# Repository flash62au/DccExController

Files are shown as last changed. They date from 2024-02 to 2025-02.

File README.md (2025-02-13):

# DccExController

Please note:

* For the foreseeable future I will not be maintaining this code base.  <br> I would recommend switching to [WiTcontroller](https://github.com/flash62au/WiTcontroller)
* I will not be providing any support for this code.
* I am no longer contactable on the DCC-EX Discord server.
* As always, you are welcome to [fork the code](forking.md) and do with it as you wish, within the limits of the licence.

## Description

A DccExController is a simple DIY, handheld controller that talks to a wThrottle Server (JMRI, DCC++EX and many others) using the Native DCC-EX protocol, exclusive to the EX-CommandStations, to control DC and DCC model trains. 

[3d Printed Case](https://www.thingiverse.com/thing:5440351)

---

## Prerequisites

1. Some basic soldering skills.  

    The components will work if just plugged together using jumpers, but they take a lot of space that way, so soldering them together is advised to make it hand held.

2. Loading the code (sketch) requires downloading of one of the IDEs, this sketch, the libraries, etc. so some experience with Arduinos is helpful, but not critical.

3. An EX-CommandStation to connect to. DccExController will ONLY work with any EX-CommandStations!
---

## Building

### Required Components

* WeMos Lite LOLIN32  (ESP32 Arduino with LiPo charger) ([Example](https://www.ebay.com.au/itm/284800618644?hash=item424f709094:g:-soAAOSwHslfC9ce&frcectupt=true))
* 3x4 Keypad  ([Example](https://www.jaycar.com.au/12-key-numeric-keypad/p/SP0770?pos=2&queryId=20aedf107668ad42c6fe1f8b7f7a9ca7))
* Polymer Lithium Ion Battery LiPo 400mAh 3.7V 502535 JST Connector (or larger capacity) ([500mAh Example](https://www.ebay.com.au/itm/133708965793?hash=item1f21ace7a1:g:tlwAAOSwfORgYqYK))
* KY-040 Rotary Encoder Module ([Example](https://www.aliexpress.com/item/1005003946689694.html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))
* OLED Display 0.96" 128x64 Blue I2C IIC SSD1306 ([Example](https://www.ebay.com.au/itm/273746192621?ssPageName=STRK%3AMEBIDX%3AIT&_trksid=p2060353.m2749.l2649))
* Case - my one was 3d printed (see below)
* Knob ([Example](https://www.jaycar.com.au/35mm-knob-matching-equipment-style/p/HK7766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))
* Wire - If you plan to solder the connections,which is the recommended approach, then stranded, coloured wire is advisable.  ([Example](https://www.jaycar.com.au/rainbow-cable-16-core-sold-per-metre/p/WM4516))

### Optional Components

* Optional: Up to 7 additional push buttons can be added, each with their own independent commands. ([Example](https://www.jaycar.com.au/red-miniature-pushbutton-spst-momentary-action-125v-1a-rating/p/SP0710))
* Optional: A 1.3" OLED Display 128x64 can be used instead of the 0.96" OLED Display 128x64 ([Example](https://www.aliexpress.com/item/32683094040.html?spm=a2g0o.order_list.order_list_main.110.25621802jRBB7y)) Note: You will need to make a small configuration change for this to work correctly.
* Optional: You can use a 4x4 keypad instead of the 3x4 keypad. Note: You will need to make a small configuration change in ``config_buttons.h`` for this to work correctly.

### Pinouts

*Standard Configuration Pinouts*
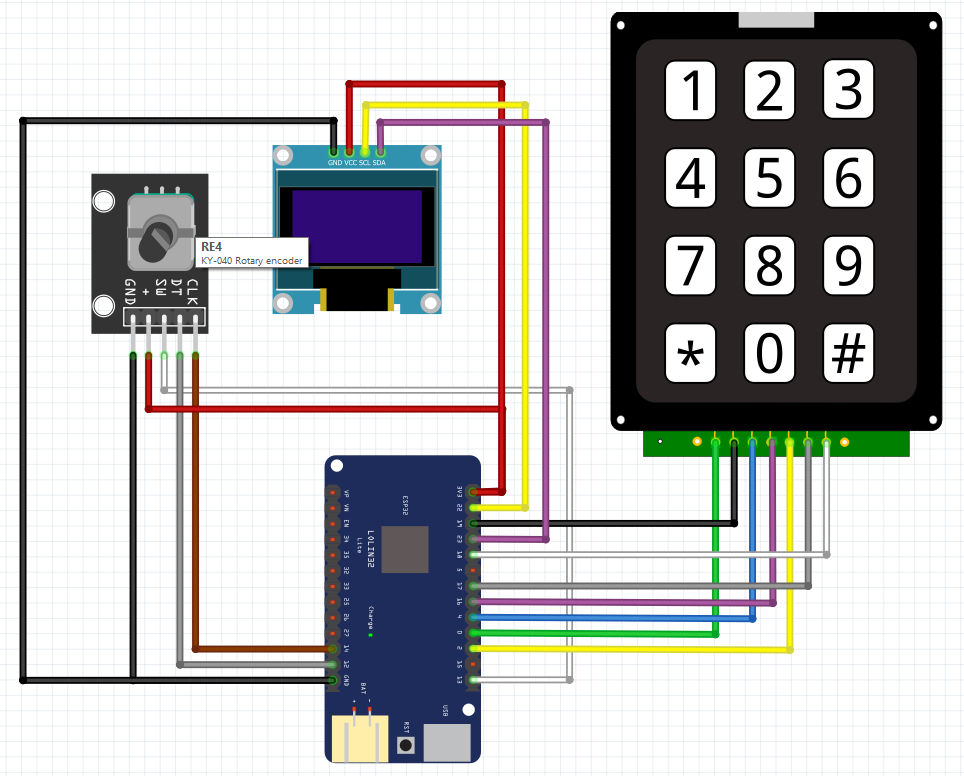
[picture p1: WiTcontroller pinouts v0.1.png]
Assembly diagram


*Pinouts for Optional Additional Buttons*
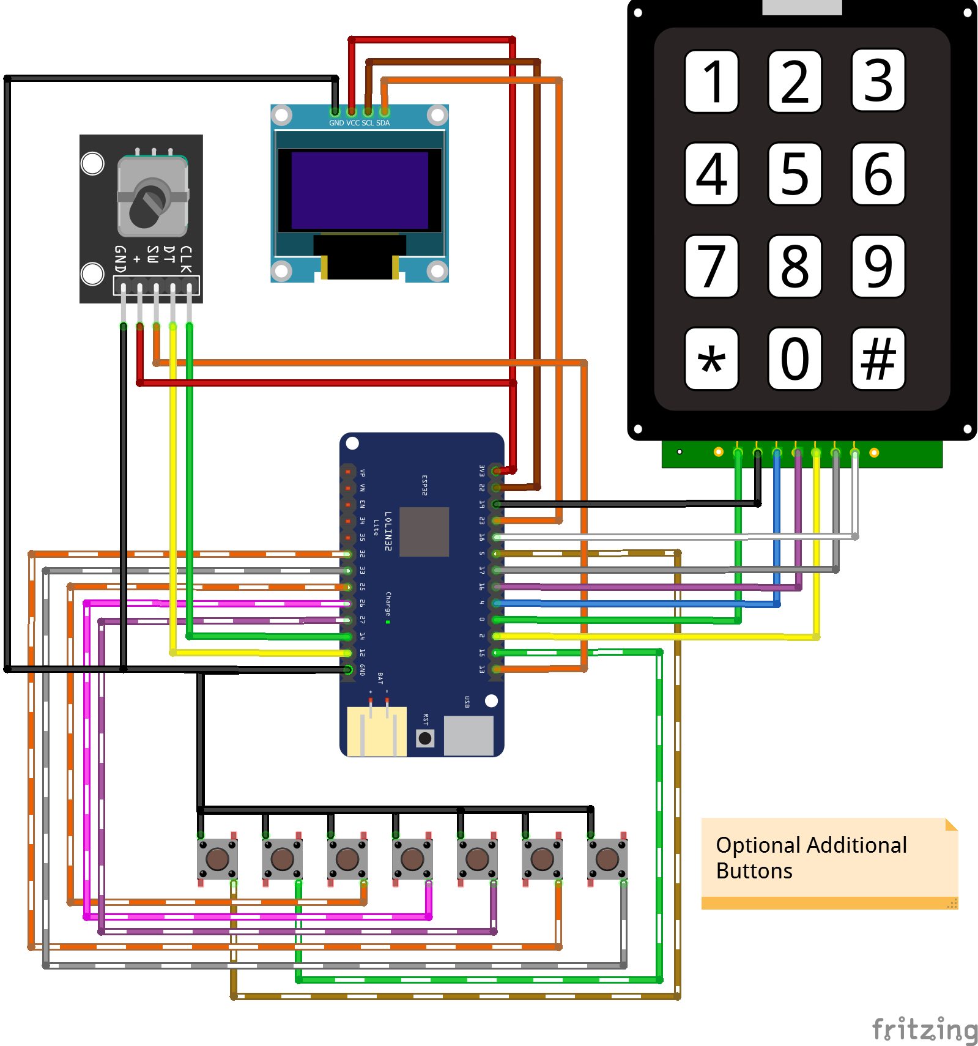
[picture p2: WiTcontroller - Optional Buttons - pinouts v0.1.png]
Assembly diagram - Optional Additional Buttons

*Default Pins for the keypads*

3x4 Keypad - Left to Right
 * C1 PIN 0
 * R0 PIN 19
 * C0 PIN 4
 * R3 PIN 16
 * C2 PIN 2
 * R2 PIN 17
 * R1 PIN 18

4x4 keypad - Left to Right
 * C0 PIN 4
 * C1 PIN 0
 * C2 PIN 2
 * C3 PIN 33
 * R0 PIN 19
 * R1 PIN 18
 * R2 PIN 17
 * R3 PIN 16
 
Notes: 

* Different keypads often arrange the pins on the base of the keypad differently.  So it is important make sure the pins on the keypad are correctly identified and adjusted as needed.

### Case

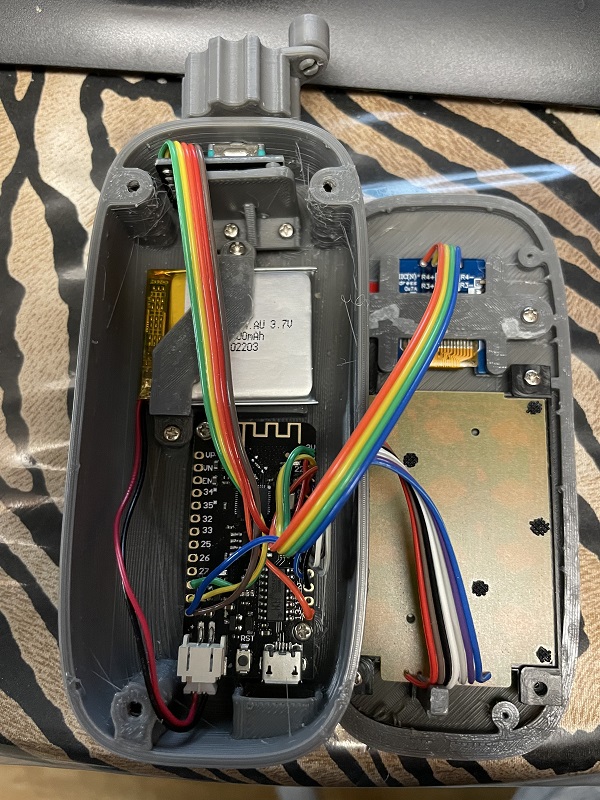
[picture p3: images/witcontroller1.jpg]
3D printer case 1


3D printed case 2

Notes:

* My case was 3D Printed for me by peteGSX (See the [Thingiverse.](https://www.thingiverse.com/thing:5440351) )
* The 3x4 keypad petGSX designed the case for came from Jaycar and is slightly narrower than the one you see in the 'deconstructed' view in the video above.
* The case requires about a dozen M2x4mm screws

* For a different take on what is possible by extending the design, have a look at: https://1fatgmc.com/RailRoad/DCC/page-5-B.html  Note, this uses the WiTcontroller code, but will work equally as well with the DccExController.

## Loading the code

The instructions below are for using the Arduino IDE and GitHub Desktop. Visual Studio Code (VSC) can be used instead of the Arduino IDE but no instructions are included here.

1. Download the Arduino IDE.  
    * Available from  https://support.arduino.cc/hc/en-us/articles/360019833020-Download-and-install-Arduino-IDE
2. Download the esp32 boards in the Arduino IDE.
    * add the esp322 support with the following instructions:  (See here for detailed instructions:  https://randomnerdtutorials.com/installing-the-esp32-board-in-arduino-ide-windows-instructions/)
        * In the Arduino IDE, go to *File* > *Preferences*
        * Enter the following into the 'Additional Board Manager URLs' field:  https://dl.espressif.com/dl/package_esp32_index.json
    * Then Use the *Boards Manager* in the *Arduino IDE* to install the esp32 board support
        * *Tools* > *Board* > *Boards Manager*
        * Search for "esp32" by Expressive Systems.  Install version 2.0.11
3. Download or clone *this* repository. (Note: if you 'clone' initially, it is easier to receive updates to the code by doing a 'fetch' subsequently.  See Notes below.)
    * Clone - **First Time**
       * Install *GitHub Desktop* from https://desktop.github.com/
       * Create a free account on GitHub and authorise the app to allow it to connect top GitHub
       * Select *file* -> *Clone Repository* - or 'Clone an repository from the internet' from the welcome page then select the 'URL' tab
       * Enter *https://github.com/flash62au/DccExController* as the URL
       * Select a local folder to install it.  The default folder for the Arduino usually looks like "...username\Documents\Arduino\". (This is a good but not essential place to put it.)
       * Click *Clone*
       * **Subsequently**  (Anytime after the first 'clone')
         * click *Fetch Origin* and any changes to the code will be bought down to you PC, but you config_buttons.h and config_network.h will not be touched.
    * Download 
       * Open *https://github.com/flash62au/DccExController*
       * Click the green "Code" button and select download zip
       * Extract the zip file to a local folder.  The default folder for the Arduino usually looks like "...username\Documents\Arduino\". This is a good but not essential place to put it.
4. Load the needed libraries to your PC. <br/> These *MUST BE* loaded from the *Library Manager* in the *Arduino IDE*. 
    * *U8g2lib.h* -  Search for "U8g2".   Install version 2.35.30 or later. <br/> (later versions should work, but go back to this 2.35.30 if you have problems.)
    * *AiEsp32RotaryEncoder.h* - search for "Ai Esp32 Rotary Encoder".  Install Version 1.4
    * *Keypad.h* - Search for "Keypad" by Mark Stanley.  Install version 3.1.1 or later. <br/> (later versions should work, but go back to this 3.1.1 if you have problems.)
    * *dccexProtocol.h* - Search for "DCCEXProtocol"  Install version 0.0.6, or later if available
   
      Note: <br/> **DO NOT** download these libraries *directly*. Use the *Library Manager*. <br/> **DO NOT** put them in the DccExController folder.

5. These should have been automatically installed when you downloaded the esp32 boards.  *YOU SHOULD NOT NEED TO DO ANYTHING SPECIFIC TO GET THESE*
    * *WiFi.h*  - https://github.com/espressif/arduino-esp32/tree/master/libraries/WiFi
    * *ESPmDNS.h* - https://github.com/espressif/arduino-esp32/blob/master/libraries/ESPmDNS

      Notes: <br/> **DO NOT** download these libraries *directly*. Use the *Boards Manager*. <br/> **DO NOT** put them in the DccExController folder. <br/> These libraries do not appear in your list of libraries, but will be available to use regardless. (The files are actually buried away in a subfolder of the ESP32 Boards library.)

6. Copy '**config_network_example.h**' to a new file to '**config_network.h**'.
    * Then edit it to include the network ssids you want to use.  (Not essential, but entering passwords via the encoder is tedious.)
7. Copy '**config_buttons_example.h**' to a new file '**config_buttons.h**'.
    * Optionally, edit this to change the mapping of the keypad buttons to specific functions.
    * Optionally, edit this to configure the additional buttons (if you have included them) to specific functions.
    * Optionally, edit this to change if you want the function buttons to display when you press #, instead of the default of showing the Key Definitions
8. Upload the sketch.  
    * Select the board type as "WEMOS LOLIN32 Lite" in the *Arduino IDE*.
    * Connect the board via USB and select the appropriate port in the *Arduino IDE*.
    * Click *Upload* 

Version Notes: 
   * DccExController version 0.23 or later requires DCCEXProtocol version 1.0.1 or later.
   * DccExController version 0.20 or later requires DCCEXProtocol version 0.0.16 or later.
   * DccExController version 0.16 or later requires DCCEXProtocol version 0.0.12 or later.
   * DccExController version 0.12 or later requires DCCEXProtocol version 0.0.10 or later.
   * DccExController version 0.02 or later requires DCCEXProtocol version 0.0.6 or later.
   * DccExController version 0.01 requires DCCEXProtocol version 0.0.3 or later.
   * The *WiFi.h* and *ESPmDNS.h* libraries were automatically installed for me when I installed the esp32 boards, however you may need to install them manually.
   * Later versions of the esp board support are available and do appear to work, but if you have difficulties version 1.0.6 appears to be stable.
   * Later versions of the libraries generally should work, but if you have difficulties use the versions listed above.
   * To get the DccExController sketch I recommend using either the git command line, or the far more friendly 'GitHub Desktop' app.  See instructions above.
   * If you receive and error related to Python, and you are on MacOs 12 and above please edit the platform file, change from python to python3 as follows; preferences->user/path/arduino/packages/hardware/esp32/version/platform.txt and edit the line that looks as follows:tools.gen_esp32part.cmd=python3 "{runtime.platform.path}/tools/gen_esp32part.py"

<br/>

---

## Using WiTController

### WiFi limitations
 
The ESP32 *cannot use the 5gHz* frequencies.  It is limited to the 2.4gHz  frequencies. 
 
It also seems to be *unable to use channels beyond 10* (and I have seen it struggle with channel 10 itself.)

## Definitions and Explanations

*DccExController* is deliberately described as a "controller" not a "throttle".  

A "Throttle" can control only one train, which may be one loco, or more than one loco in consist/MU.

*DccExController*, as a "controller", **contains up to six (6) "throttles"**. Each which can control any number of locos in consist/MU. You can swap between throttles at will (``keypad 5``) to select which locos/consists/MUs you one you are manipulating at a given time. While you can only manipulate one loco/consist/MU at at time, the other continue running at the setting you gave it.

## Features

**Currently functioning:**
- Provides a list of discovered SSIDs with the ability to choose one. When you select one:
  - if it is one in your specified list (in the sketch), it will use that specified password 
  - if it is a EX-CommandStation in access Point mode, it will guess the password
  - otherwise it will ask to enter the password (Use the rotary encoder to choose each character and the encoder button to select it.  * = backspace.  # = enter the password.) 
- Optionally provides a list of SSIDs with the specified passwords (in the sketch) to choose from
- Auto-connects to the first found EX-CommandStation if only one found, otherwise 
  - Asks which to connect to
  - If none found will ask to enter the IP Address and Port
  - Guesses the  IP address and Port for EX-CommandStations using Access Point mode
  - optionally can add a #define (a preference) to disable this auto connect feature
- Rudimentary on-the-fly consists
- Assign commands directly to the 1-9 buttons (in the sketch) (see list below)
  - This is done in config_button.h
- Optional ability to assign commands directly to the 1-7 additional buttons (in the sketch) (see list below)
  - These are defined config_button.h
- Command menu (see below for full list) including:
  - Able to select and deselect locos 
    - by their DCC address, via the keypad
      - On NCE systems, a leading zero (0) will force a long address
    - from the first 50 locos in the roster
  - Able to select multiple locos to create a consist
    - Able to change the facing of the additional locos in the consists (via the 'extra' menu after selection)
  - Able to activate any function (0-31)
    - Showing of the roster function labels (from the EX-CommandStation if provided)
    - Quick access to the functions by pressing #. Temporarily enabled via the Extras menu (or permanently enabled in config_button.h)
    - Limited ability to configure which functions are sent to the first or all locos in a consist (defined in config_button.h)
  - Able to throw/close turnouts/points
    - from the address
    - from the first 50 turnouts/points in the server list
  - Able to activate routes
    - from their address
    - from the first 50 routes in the server list
  - Set/unset a multiplier for the rotary encoder
  - Power Track On/Off
  - Disconnect / Reconnect
  - Put ESP32 in deep sleep and restart it
- Have up to 6 throttles, each with an unlimited number of locos in consist. Default is 2 throttles, which can be increased or decreased temporarily via the Extras menu (or permanently enabled in config_button.h)
- Limited dealing with unexpected disconnects.  It will throw you back to the WiThrottle Server selection screen.
- Boundary between short and long DCC addresses can be configured in config_buttons.h
- The default speed step (per encoder click) can be configured in config_buttons.h
- The controller will automatically shut down if no SSID is selected or entered in 4 minutes (to conserve the battery)

**ToDo:**
- Speed button repeat (i.e. hold the button down)
- Deal with unexpected disconnects better
  - automatic attempt to reconnect
- Keep a list of IP addresses and ports if mDNS doesn't provide any
- Remember (for the current session only) recently selected locos
- functions
 - Latching / non-latching for the functions to be provided by the roster entry of EEX-CommandStation

### Command menu:
- 0-9 keys = pressing these directly will do whatever you has been preset in the sketch for them to do  (see \# below)
- \* = Menu:  The button press following the \* is the actual command:
  - 1 = Add loco.  
     - Followed by the loco number, followed by \# to complete.  e.g. to select loco 99 you would press '\*199\#'
     - or \# alone to show the roster   \# again will show the next page
  - 2 = release loco:
     - Followed by the loco number, followed by \# to release an individual loco.  e.g. to deselect the loco 99 you would press '\*299\#'
     - Otherwise followed directly by \#  to release all e.g. '\*2\#'
  - 3 = Toggle direction.
  - 4 = Set / Unset a 2 times multiplier for the rotary encoder dial.
  - 5 = Throw turnout/point.  
     - Followed by the turnout/point number, followed by the \# to complete.  e.g. Throw turnout XX12 '\*512\#'  (where XX is a prefix defined in the sketch) 
     - or \# alone to show the list from the server   \# again will show the next page
  - 6 = Close turnout.    
     - Followed by the turnout/point number, followed by \# to complete.  e.g. Close turnout XX12 '\*612\#'  (where XX is a prefix defined in the sketch)
     - or \# alone to show the list from the server
  - 7 = Set Route.    
      - Followed by the Route number, followed by \# to complete.  e.g. to Set route XX:XX:0012 '\*60012\#'  (where \'XX:XX:\' is a prefix defined in the sketch)
      - or \# alone to show the list from the server   \# again will show the next page
  - 0 = Function button. Followed by...
      - the function number, Followed by \# to complete.  e.g. to set function 17 you would press '\*017\#'
      - \# alone, to show the list of functions.
  - 8 = Track Power On/Off.
  - 9 = Extras. Followed by...
      - 0 then \# to toggle the action the the \# key does as a direct action, either to show the direct action key definitions, or the Function labels.  
      - 1 to change the facing of locos in a consist.
      - 3 to toggle the heartbeat check.
      - 4 to increase the number of available throttle (up to 6)
      - 5 to decrease the number of available throttle (down to 1)
      - 6 then \# to Disconnect/Reconnect.  
      - 7 (or 9) then \# to put into deep sleep
Pressing '\*' again before the '\#' will terminate the current command (but not start a new command)
 - \# = Pressing # alone will show the function the the numbered keys (0-9) perform, outside the menu.
       Optionally, you can configure it so that the the Function labels from the roster show 

Pressing the Encoder button while the ESP32 is in Deep Sleep will revive it.

### Default number key assignments (0-9)  (outside the menu)

* 0 = FUNCTION_0 (DCC Lights)
* 1 = FUNCTION_1 (DCC Bell)
* 2 = FUNCTION_3 (DCC Horn/Whistle)
* 3 = FUNCTION_3
* 4 = FUNCTION_4
* 5 = NEXT_THROTLE
* 6 = SPEED_MULTIPLIER
* 7 = DIRECTION_REVERSE
* 8 = SPEED_STOP
* 9 = DIRECTION_FORWARD

### Allowed assignments for the 0-9 keys:

Note: you need to edit config_buttons.h to alter these assignments   (copy config_buttons_example.h)
- FUNCTION_NULL   - don't do anything
- FUNCTION_0 - FUNCTION_31
- SPEED_STOP
- SPEED_UP
- SPEED_DOWN
- SPEED_UP_FAST
- SPEED_DOWN_FAST
- SPEED_MULTIPLIER
- E_STOP   - E Stop all locos on all throttles
- E_STOP_CURRENT_LOCO - E Stop locos on current throttle only
- POWER_TOGGLE
- POWER_ON
- POWER_OFF
- SHOW_HIDE_BATTERY
- DIRECTION_TOGGLE
- DIRECTION_FORWARD
- DIRECTION_REVERSE
- NEXT_THROTTLE
- SPEED_STOP_THEN_TOGGLE_DIRECTION   - stops the loco if moving.  Toggles the direction if stationary.
- MAX_THROTTLE_INCREASE    - change the number of available throttles on-the-fly
- MAX_THROTTLE_DECREASE    - change the number of available throttles on-the-fly

### instructions for optional use of a potentiometer (pot) instead of the encoder for the throttle

config_buttons.h can include the following optional defines:

  * \#define USE_ROTARY_ENCODER_FOR_THROTTLE false
  * \#define THROTTLE_POT_PIN 39
  * \#define THROTTLE_POT_USE_NOTCHES true 
  \#define THROTTLE_POT_NOTCH_VALUES {1,585,1170,1755,2340,2925,3510,4094}
  * \#define THROTTLE_POT_NOTCH_SPEEDS {0,18,36,54,72,90,108,127} 

  If ``USE_ROTARY_ENCODER_FOR_THROTTLE`` is set to ``false`` the rotary encoder is ignored and a pot on the pin defined with ``THROTTLE_POT_PIN`` will be used instead.

  You must specify the PIN to be used.  Currently PINs 34, 35 and 39 are the only ones that cannot be used by the app for other purposes, so these are the safest to use.  This should be connected to the centre pin of the pot. The 3v and GND should be connected to the outer pins of the pot.

  The pot can be set to have 8 defined 'notches' (the default) or just a linear value.

  If you want to have the 8 notches:
  
  a) You must define the values the pot will send at each of 8 points - ``THROTTLE_POT_NOTCH_VALUES``.  Note that you should avoid the value zero (0) for notch zero.  Use at least 1 instead.

    The example values above are useble for a 10k ohm pot but any value pot can be used. Just adjust the numbers.

  b) You must define what speed should be sent for each notch - ``THROTTLE_POT_NOTCH_SPEEDS``

  If you want a linear speed instead of notches:

  a) You must define the values the pot will send at at zero throw and full throw in the first and last of the 8 values in ``THROTTLE_POT_NOTCH_VALUES``.  The other values will be ignored but you still need to include 8 values.  (They can be zero.)  Note that you should avoid the value zero (0) for notch zero.  Use at least 1 instead.

  Sumner Patterson is developing an app to help find the appropriate pot values for the ``THROTTLE_POT_NOTCH_VALUES``.

---

### Instructions for optional use of a voltage divider to show the battery charge level

*Pinouts for Optional Battery Monitor*
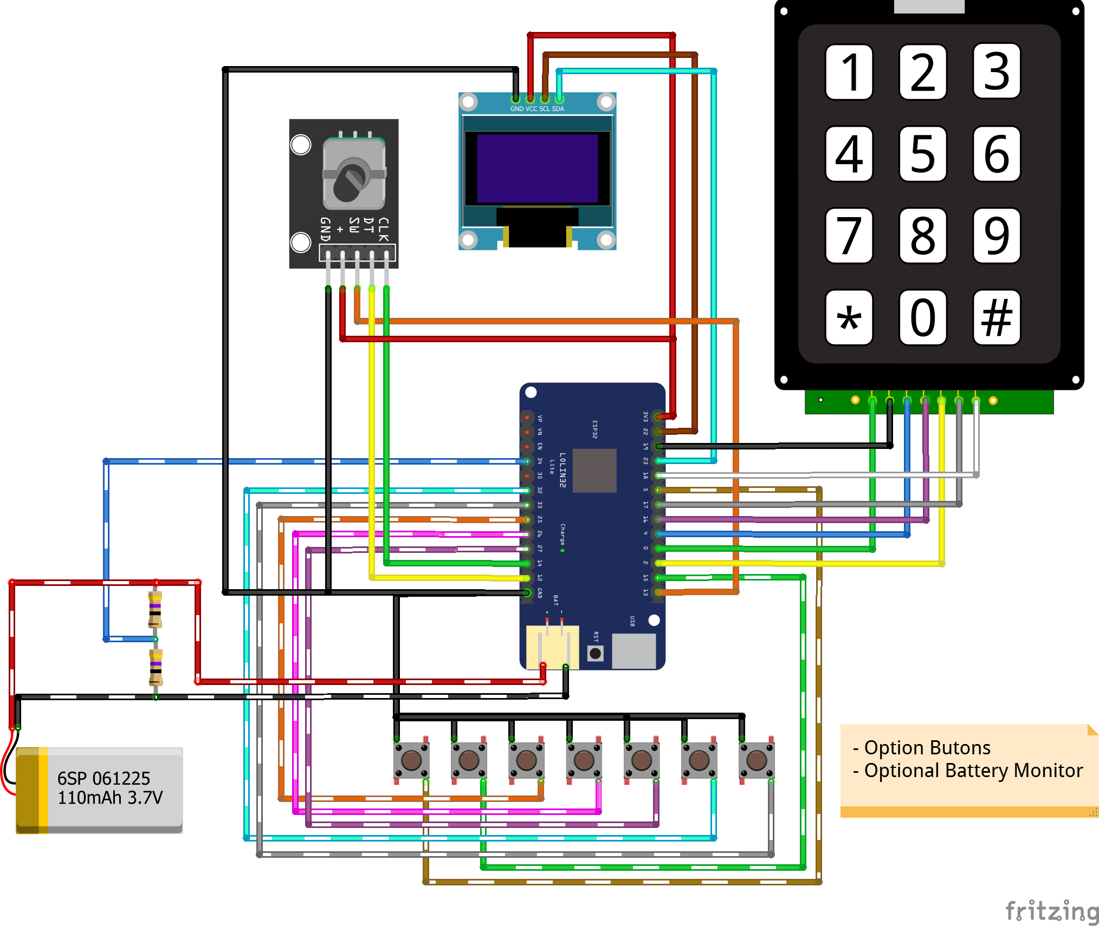
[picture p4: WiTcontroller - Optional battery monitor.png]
Assembly diagram - Optional Battery Monitor


See diagram above for how to wire in the volage divider.  47k resistors are used, but this can be varied as long as the output to the pin is limited to below 3.3v. See additional information related to the Pangodream Library that DccExController uses here... https://www.pangodream.es/tag/18650-ion-li

The diagram has the voltage divider spliced into battery leads, but you can solder the positive in to the back of the battery connector (on the ESP32) if you prefer. The ground can be taken from any ground pin.

*To enable the battery monitor*, set the following to ``true``. The default is ``false``.

``#define USE_BATTERY_TEST true``

*To set which pin to use.* The default is ``34``.  In theory 34, 35, 36, or 39 should be able to be used, but only 34 and 36 have been tested.   (36 is marked 'VP' on the board.  39 is marked 'VN' on the board.)

``#define BATTERY_TEST_PIN 34``

If the battery does not show 100% when plugged into the charger, you may need to adjust this value. The default is ``1.7``.

``#define BATTERY_CONVERSION_FACTOR 1.7``

    To help work out the correct BATTERY_CONVERSION_FACTOR, you can enable so serial monitor message that will assist.

    In your ``config_buttons.h`` add (or uncomment) these defines:
    
      #define WITCONTROLLER_DEBUG    0
      #define DEBUG_LEVEL   2

    DEBUG_LEVEL must be 2 or greater

    a) Make sure your battery is fully charged.
    b) Upload the code and open the serial monitor. 
    c) Wait. Don't connect.
    You will see lines like...

      BATTERY TestValue: 100 (10003)
      BATTERY lastAnalogReadValue: 2491 (10003)
      BATTERY If Battery full, BATTERY_CONVERSION_FACTOR should be: 1.69 (10014)

    Let it run for a while.
    d) Note one of the recommend values (it will vary a bit) and enter it into the define in your config_buttons.h
    e) Re-upload code and connect to a server
    f) Confirm that the battery reads 100% (repeat if not)
    g) Run the HandCab on battery for few hours and confirm the battery level is droping at an expected rate. (adjust the conversion factor if not.)

*To show the calculated percentage*, set the following to ``true`` The default is ``false``.

``#define USE_BATTERY_PERCENT_AS_WELL_AS_ICON true``

*To force the HandCab to go to sleep at a specific level*, set this value. (e.g. to 3 or 5.) A value of less than zero (e.g. -1) will disable the feature. By default it is disabled (-1).

``#define USE_BATTERY_SLEEP_AT_PERCENT 3``

The display of the battery can be temporarily toggled by setting a key or button to ``SHOW_HIDE_BATTERY``.  The display will cycle between none, icon only and icon plus percent value. Note that ``USE_BATTERY_TEST`` must be set to `true` for this to have any effect.

Note: 
I recommend adding a physical power switch to disconnect the battery as this feature will, slowly, continually drain the battery, even when not being used.

<br />

---
---

## Modifying the code

If you plan to modify the code it is recommended that you create your own GitHub fork of my repository and post your mods there.

[Instructions on how to do so are here](forking.md).

---
---

## Change Log

### V0.31
- bug fix.  roster entries >60 would cause a crash

### V0.30
- add define for ``CUSTOM_APPNAME``

### V0.29
- support UTF8 fonts better

### V0.28
- able to override the default font (not recommended)

### V0.27
- change to a font that has accented characters

### V0.26
- fix bug introduced by changes in v1.0.1 of the Protocol library such that the direction of non-roster locos could not be changed.

### V0.25
- bug fix for when using the Arduino IDE

### V0.24
- added support for ``BATTERY_CONVERSION_FACTOR`` define

### V0.23
- make roster momentary functions obey momentary if selected from the menu
- moved the battery indicator to the top row
- added the ``BATTERY_CONVERSION_FACTOR`` define

### V0.22
- fix for ``E_STOP_CURRENT_LOCO``  

### V0.21
- automated fix the latest versions of the ESP32 Board Library (3.0.0 and later) having renamed an attribute. The code now automatically adjusts for this.  

### V0.20
- support for 4x4 keypad
- support for custom commands
- workaround for the latest versions of the ESP32 Board Library (3.0.0 and later) have renamed an attribute. 

### V0.18 and V0.19
- minor format change 

### V0.18
- added auto deep sleep on low battery 

### V0.17
 - support for optionally using a voltage divider to show the battery charge level
 - remove some of the debug messages 

### V0.16
 - Create fake heartbeat to help keep the connection alive 

### V0.15
 - button and display PIN configurations moved to defines that can be overridden in personal config_buttons_etc.h files
 - no functional changes

### V0.14
 - All menu text moved to defines that can be overridden in personal config_buttons_etc.h files
 - no functional changes

### V0.13
 - minor bug fix

### V0.12
 - support for Broadcast Messages. - now requires DccExProtocol Library version 0.0.10 or later

### V0.11
 - bug fix
 - additional logging
 
### V0.10
 - Additional logging
 - addition of code and a #define SEARCH_ROSTER_ON_ENTRY_OF_DCC_ADDRESS  (from FeliceV)

### V0.09
 - fix for the debounce of the rotary encoder button. Will now ignore rotations when the button is pressed for (default) 200ms.  The #define for the debounce has been moved from config_keypad_etc.h to config_buttons as: #define ROTARY_ENCODER_DEBOUNCE_TIME 200

### V0.08
- Will now use function latching from the roster, if the loco is selected from the roster
- F0 default to latching - can be overridden (see config_buttons_example.h)

### V0.07
- F0 default to latching - can be overridden (see config_buttons_example.h)

### V0.06
- temporary solution for latching buttons
- F1 and F2 default to momentary - can be overridden (see config_buttons_example.h)

### V0.05
- option to specify/increase the buffer size

### v0.04
- option to autoconnect to first defined ssid

### v0.03
- support for 32 functions

### v0.02
- Fix loading of the function labels

### v0.01
- initial release

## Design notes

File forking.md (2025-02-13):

# Instructions for Forking the code

If you plan to modify the code it is recommended that you create your own GitHub fork of my repository and post your mods there.

That way:

* It is easier to accept any changes I make in my origin repository. </br> Git will generally merge the changes automatically. (Rather you than manually patching each each time.)
* ~~You can, if you wish, send your changes to me, via Pull Requests from your fork, for inclusion in the origin~~
* It is easier for other people to pull down your version, and any subsequent changes to your version, to try it out without effecting their other versions. 

## Required Software

* GitHub Desktop
* Arduino IDE or VSCode (VSC)

## Procedure

### Procedure Overview

Ideally the documentation cycle would look like this..

Changes to the original would be pulled down from the original repository directly to your local (PC) repository.  You would push your changes to your GitHub website repository. Then create a *Pull request* to send them to the original for review.

While this is possible, both **GitHub Desktop** and **VSCode** make it extremely cumbersome to do so.

*So instead a slightly longer approach is described below...*

Changes to the original would be pulled down from the original repository to your GitHub website repository with a *Pull Request*.  You will then pull those changes to you local (PC) repository. You will push your changes to your GitHub website repository. Then create a *Pull Request* to send them to the original for review.

There are a number of possible ways to do this but the instructions below are reasonably simple and work:

One time only:

1. Cloning the repository on the **GitHub website**
2. Using **GitHub Desktop** to download the repository to your PC

Ongoing:

3. Opening the repository in the **Arduino IDE** or **VSCode**
4. Making your changes
5. Previewing your changes on your PC
6. Using **GitHub Desktop** to *push* your changes back to your clone of the Repository on GitHub
7. Creating a *pull request* to send your changes for review

You will periodically need to update your repository:

1. Create a pull request on the **GitHub website** to get any changes from the original repository to your repository on GitHub website
2. Use **GitHub Desktop** to pull the changes to your repository on your PC

One time only
----

#### 1. Cloning the repository on GitHub website

1. First you will need to create an account on Github if you don't already have one.
2. Go to the original repository ``https://github.com/flash62au/DccExController``
3. Click on the `Fork` button and create a new fork.

You will now have a new fork located at ``https://github.com/<your_account_name>/DccExController`` (or whatever you called it).  Take note of this for the next step.

#### 2. Download the repository to your PC with GitHib Desktop

In **GitHub Desktop**:

1. Select `File` --> `Clone Repository`
2. Enter the name of you repository ``<your_account_name>/DccExController`` (or whatever you called it).
3. Select a location on your PC to store the repository.
4. Click `Clone`

A copy of the repository should now be on the PC.

If you are using VSCode, you can open it in VSCode by selecting ``Repository -> Open in Visual Studio Code``

Ongoing
-------

#### 3. Open the repository in VSCode

You can open the repository in the Arduino IDE or VSCode at any time by using `File` --> `Open Folder` and navigating to the folder you selected in step 2.

You can subsequently open the repository in VSCode using `File` --> `Open Recent` and selecting the repository name.

You can subsequently open the repository in VSCode from **GitHub Desktop**.

### 4. Make your changes

You can use the navigation tree on the left to find the file you want to change. Clicking on a file will open it in the edit window.

### 5. Push your changes to your GitHub repository

You will need to

* Commit your changes
* Push your changes

In **GitHub Desktop**:

* Open/select the repository
* note and review the changes that have been made
* Add a ``Summary`` of your changes
* Add a ``Description`` of your changes, if the summary is not sufficient space
* click `Commit to Main`
* click `Push origin`

### 6. Creating a *pull request* to send your changes for review

1. Open the **GitHub website**
2. Open/select your repository ``https://github.com/<your_account_name>/DccExController`` (or whatever you called it)

On the 'code' page you should see "This branch is *x* commit(s) ahead of DCC-EX/dcc-ex.github.io:sphinx."

3. Click on the `x commit(s) ahead of` hyperlink
5. Confirm or add to the title and documentation fields
6. Click on the `Create pull request` button

This creates a pull request to be reviewed by the documentation team

Periodic
---------

To see the changes that other people have made to the original repository you need to periodically refresh your repository on both GitHub website and locally 

#### a. Get any changes to your repository on GitHub website

1. Open the **GitHub website**
2. open/select your repository ``https://github.com/<your_account_name>/DccExController`` (or whatever you called it)

On the 'code' page you should see "This branch is *x* commit(s) behind flash62au/DccExController."

If does not say you are 'behind' there is nothing to do.  Stop here.

If you are behind...

3. Click on the `x commit(s) behind` hyperlink
5. Add to the title and/or documentation fields.  This does not matter so entering just ``Catchup`` is fine.
6. Click on the `Create pull request` button
7. Click on the `Merge pull request` button
7. Click on the `Confirm merge` button

Any changes are now also in your repository on the GitHub website.

### b. Pull the changes to your repository on your PC

In **GitHub Desktop**:

1. Click on the `Fetch origin` button`

Any changes are now also in your repository on PC.

----

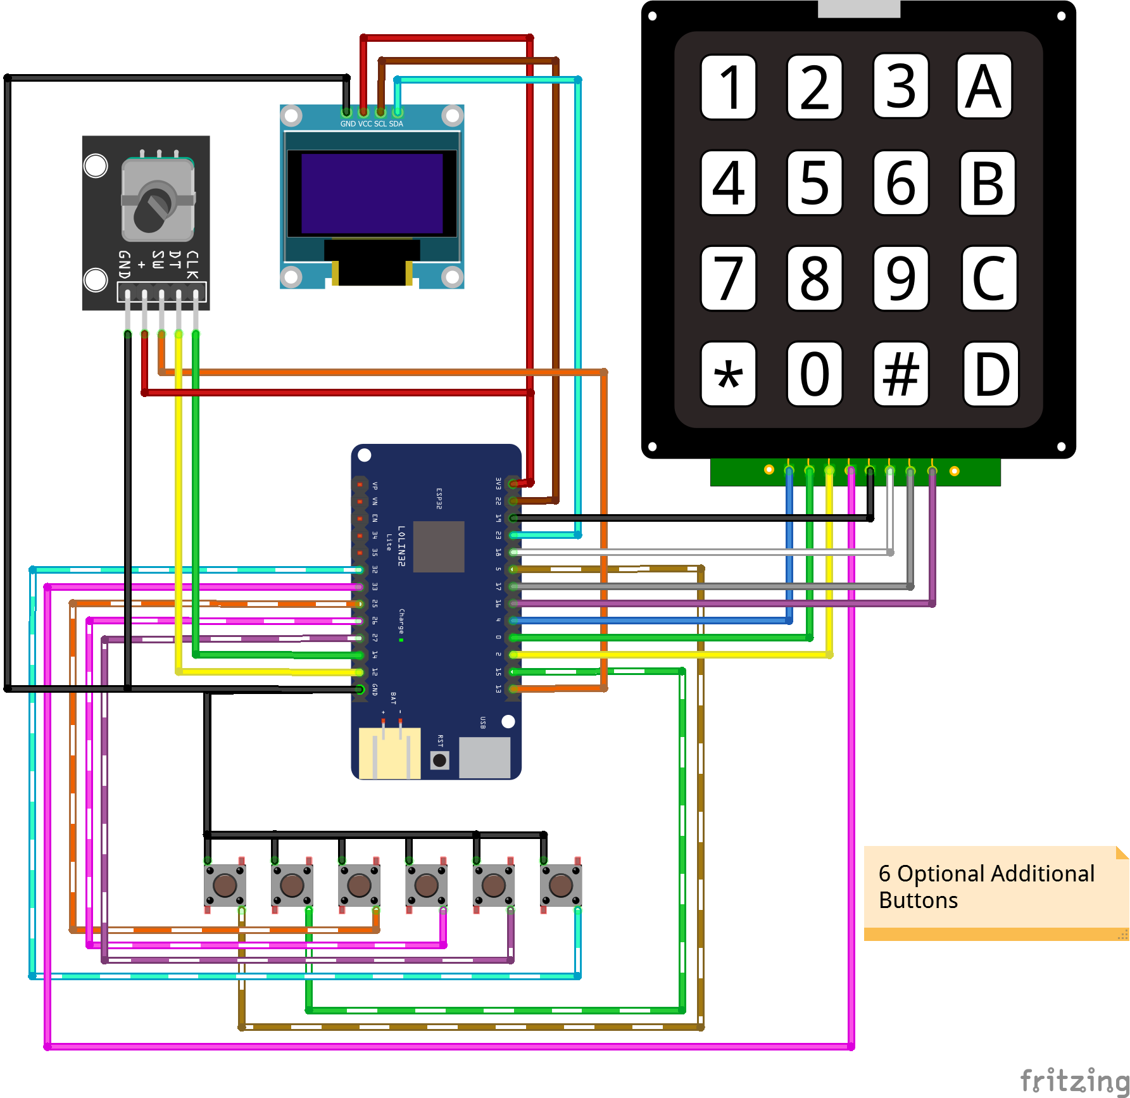
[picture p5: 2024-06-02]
WiTcontroller - 4x4 keypad, Optional Buttons - pinouts v0.1.png

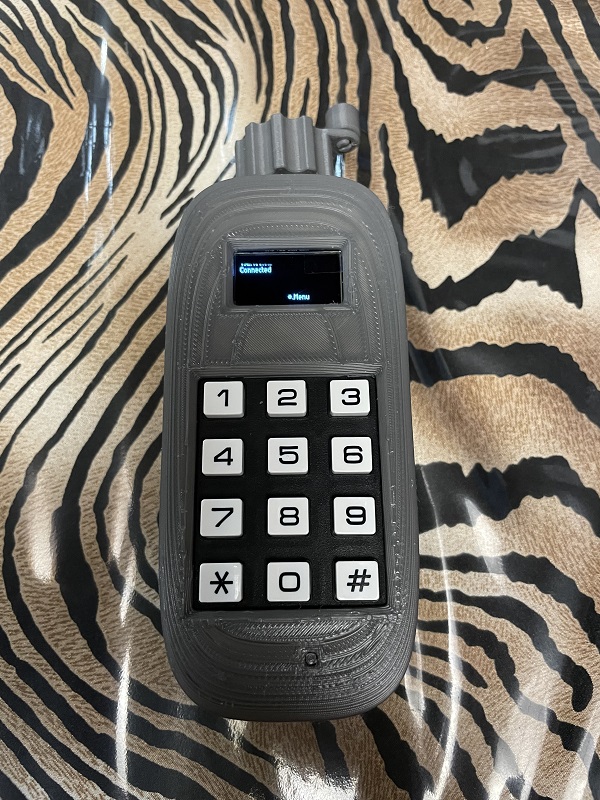
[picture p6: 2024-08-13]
images/witcontroller2.jpg

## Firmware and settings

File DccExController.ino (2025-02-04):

/**
 * This app turns the ESP32 into a Bluetooth LE keyboard that is intended to act as a dedicated
 * gamepad for the JMRI or any wiThrottle server.

  Instructions:
  - Update WiFi SSIDs and passwords as necessary in config_network.h.
  - Flash the sketch 
 */

#include <string>

// Use the Arduino IDE 'Boards' Manager to get these libraries
// They will be installed with the 'ESP32' Board library
// DO NOT DOWNLOAD THEM DIRECTLY!!!
#include <WiFi.h>                 // https://github.com/espressif/arduino-esp32/tree/master/libraries/WiFi     GPL 2.1
#include <ESPmDNS.h>              // https://github.com/espressif/arduino-esp32/blob/master/libraries/ESPmDNS  GPL 2.1

// use the Arduino IDE 'Library' Manager to get these libraries
// DO NOT DOWNLOAD THEM DIRECTLY!!!
#include <DCCEXProtocol.h>        // https://github.com/DCC-EX/DCCEXProtocol                                    
#include <AiEsp32RotaryEncoder.h> // https://github.com/igorantolic/ai-esp32-rotary-encoder                    GPL 2.0
#include <Keypad.h>               // https://www.arduinolibraries.info/libraries/keypad                        GPL 3.0
#include <U8g2lib.h>              // https://github.com/olikraus/u8g2  (Just get "U8g2" via the Arduino IDE Library Manager)   new-bsd

// this library is included with the WiTController code
#include "Pangodream_18650_CL.h"  // https://github.com/pangodream/18650CL  

// create these files by copying the example files and editing them as needed
#include "config_network.h"       // LAN networks (SSIDs and passwords)
#include "config_buttons.h"       // keypad buttons assignments

// DO NOT ALTER these files
#include "config_keypad_etc.h"    // hardware config - GPIOs - keypad, encoder; oled display type
#include "static.h"
#include "actions.h"
#include "DccExController.h"
#include "Throttle.h"

#if DCCEXCONTROLLER_DEBUG == 0
 #define debug_print(params...) Serial.print(params)
 #define debug_println(params...) Serial.print(params); Serial.print(" ("); Serial.print(millis()); Serial.println(")")
 #define debug_printf(params...) Serial.printf(params)
#else
 #define debug_print(...)
 #define debug_println(...)
 #define debug_printf(...)
#endif

// *********************************************************************************

#ifndef MAX_BUFFER_SIZE
 #define MAX_BUFFER_SIZE 500
#endif
#ifndef MAX_COMMAND_PARAMS
 #define MAX_COMMAND_PARAMS 50
#endif

int keypadUseType = KEYPAD_USE_OPERATION;
int encoderUseType = ENCODER_USE_OPERATION;
int encoderButtonAction = ENCODER_BUTTON_ACTION;

bool menuCommandStarted = false;
String menuCommand = "";
bool menuIsShowing = false;

String oledText[18] = {"", "", "", "", "", "", "", "", "", "", "", "", "", "", "", "", "", ""};
bool oledTextInvert[18] = {false, false, false, false, false, false, false, false, false, 
                           false, false, false, false, false, false, false, false, false};

int currentSpeed[6];   // set to maximum possible (6)
Direction currentDirection[6];   // set to maximum possible (6)
int speedStepCurrentMultiplier = 1;

TrackPower trackPower = PowerUnknown;

// encoder variables
bool circleValues = true;
int encoderValue = 0;
int lastEncoderValue = 0;

// battery test values
bool useBatteryTest = USE_BATTERY_TEST;
#if USE_BATTERY_TEST
  #if USE_BATTERY_PERCENT_AS_WELL_AS_ICON
    ShowBattery showBatteryTest = BATTERY_ICON_AND_PERCENT;
  #else 
    ShowBattery showBatteryTest = BATTERY_ICON_ONLY;
  #endif
#else
  ShowBattery showBatteryTest = BATTERY_NONE;
#endif
int batteryTestPin = BATTERY_TEST_PIN;
bool useBatteryPercentAsWellAsIcon = USE_BATTERY_PERCENT_AS_WELL_AS_ICON;
int lastBatteryTestValue = 0; 
double lastBatteryCheckTime = 0;
Pangodream_18650_CL BL(BATTERY_TEST_PIN, BATTERY_CONVERSION_FACTOR);

// server variables
// bool ssidConnected = false;
String selectedSsid = "";
String selectedSsidPassword = "";
int ssidConnectionState = CONNECTION_STATE_DISCONNECTED;

// ssid password entry
String ssidPasswordEntered = "";
bool ssidPasswordChanged = true;
char ssidPasswordCurrentChar = ssidPasswordBlankChar; 

IPAddress selectedWitServerIP;
int selectedWitServerPort = 0;
String selectedWitServerName ="";
int noOfWitServices = 0;
int dccexConnectionState = CONNECTION_STATE_DISCONNECTED;

//found wiThrottle servers
IPAddress foundWitServersIPs[maxFoundWitServers];
int foundWitServersPorts[maxFoundWitServers];
String foundWitServersNames[maxFoundWitServers];
int foundWitServersCount = 0;
bool autoConnectToFirstDefinedServer = AUTO_CONNECT_TO_FIRST_DEFINED_SERVER;
bool autoConnectToFirstWiThrottleServer = AUTO_CONNECT_TO_FIRST_WITHROTTLE_SERVER;

//found ssids
String foundSsids[maxFoundSsids];
long foundSsidRssis[maxFoundSsids];
bool foundSsidsOpen[maxFoundSsids];
int foundSsidsCount = 0;
int ssidSelectionSource;
double startWaitForSelection;

// wit Server ip entry
String witServerIpAndPortConstructed = "###.###.###.###:#####";
String witServerIpAndPortEntered = DEFAULT_IP_AND_PORT;
bool witServerIpAndPortChanged = true;

// roster variables
int rosterSize = 0;
int rosterIndex[maxRoster]; 
String rosterName[maxRoster]; 
int rosterAddress[maxRoster];

int page = 0;
int functionPage = 0;
bool functionHasBeenSelected = false;

bool searchRosterOnEntryOfDccAddress = SEARCH_ROSTER_ON_ENTRY_OF_DCC_ADDRESS;

// Broadcast msessage
String broadcastMessageText = "";
long broadcastMessageTime = 0;

// remember oled state
int lastOledScreen = 0;
String lastOledStringParameter = "";
int lastOledIntParameter = 0;
bool lastOledBooleanParameter = false;

// turnout variables
int turnoutListSize = 0;
int turnoutListIndex[maxTurnoutList]; 
String turnoutListSysName[maxTurnoutList]; 
String turnoutListUserName[maxTurnoutList];
bool turnoutListState[maxTurnoutList];

// route variables
int routeListSize = 0;
int routeListIndex[maxRouteList]; 
String routeListSysName[maxRouteList]; 
String routeListUserName[maxRouteList];

// throttles
Throttle* throttles[6];   // set to maximum possible (6 throttles)

// function states
bool functionStates[6][MAX_FUNCTIONS];   // set to maximum possible (6 throttles)

// function labels
String functionLabels[6][MAX_FUNCTIONS];   // set to maximum possible (6 throttles)
// function momentary
bool functionMomentary[6][MAX_FUNCTIONS]; // set to maximum possible (6 throttles)

// consist function follow
int functionFollow[6][MAX_FUNCTIONS];   // set to maximum possible (6 throttles)

// speedstep
int currentSpeedStep[6];   // set to maximum possible (6 throttles)

// throttle
int currentThrottleIndex = 0;
int maxThrottles = MAX_THROTTLES;

int heartBeatPeriod = 10; // default to 10 seconds
long lastHeartBeatSentTime;
long lastServerResponseTime;
bool heartbeatCheckEnabled = true;

// used to stop speed bounces
long lastSpeedSentTime = 0;
int lastSpeedSent = 0;
// int lastDirectionSent = -1;
int lastSpeedThrottleIndex = 0;

// don't alter the assignments here
// alter them in config_buttons.h

static unsigned long rotaryEncoderButtonLastTimePressed = 0;
const int rotaryEncoderButtonEncoderDebounceTime = ROTARY_ENCODER_DEBOUNCE_TIME;   // in miliseconds

const bool encoderRotationClockwiseIsIncreaseSpeed = ENCODER_ROTATION_CLOCKWISE_IS_INCREASE_SPEED;
// false = Counterclockwise  true = clockwise

const bool toggleDirectionOnEncoderButtonPressWhenStationary = TOGGLE_DIRECTION_ON_ENCODER_BUTTON_PRESSED_WHEN_STATIONAY;
// true = if the locos(s) are stationary, clicking the encoder button will toggle the direction

//4x3 keypad only uses 0-9
//4x4 uses all 14 
int buttonActions[14] = { CHOSEN_KEYPAD_0_FUNCTION,
                          CHOSEN_KEYPAD_1_FUNCTION,
                          CHOSEN_KEYPAD_2_FUNCTION,
                          CHOSEN_KEYPAD_3_FUNCTION,
                          CHOSEN_KEYPAD_4_FUNCTION,
                          CHOSEN_KEYPAD_5_FUNCTION,
                          CHOSEN_KEYPAD_6_FUNCTION,
                          CHOSEN_KEYPAD_7_FUNCTION,
                          CHOSEN_KEYPAD_8_FUNCTION,
                          CHOSEN_KEYPAD_9_FUNCTION,
                          CHOSEN_KEYPAD_A_FUNCTION,
                          CHOSEN_KEYPAD_B_FUNCTION,
                          CHOSEN_KEYPAD_C_FUNCTION,
                          CHOSEN_KEYPAD_D_FUNCTION
};

// text that will appear when you press #
const String directCommandText[4][3] = {
    {CHOSEN_KEYPAD_1_DISPLAY_NAME, CHOSEN_KEYPAD_2_DISPLAY_NAME, CHOSEN_KEYPAD_3_DISPLAY_NAME},
    {CHOSEN_KEYPAD_4_DISPLAY_NAME, CHOSEN_KEYPAD_5_DISPLAY_NAME, CHOSEN_KEYPAD_6_DISPLAY_NAME},
    {CHOSEN_KEYPAD_7_DISPLAY_NAME, CHOSEN_KEYPAD_8_DISPLAY_NAME, CHOSEN_KEYPAD_9_DISPLAY_NAME},
    {"* Menu", CHOSEN_KEYPAD_0_DISPLAY_NAME, "# This"}
};

bool oledDirectCommandsAreBeingDisplayed = false;
#ifdef HASH_SHOWS_FUNCTIONS_INSTEAD_OF_KEY_DEFS
  bool hashShowsFunctionsInsteadOfKeyDefs = HASH_SHOWS_FUNCTIONS_INSTEAD_OF_KEY_DEFS;
#else
  bool hashShowsFunctionsInsteadOfKeyDefs = false;
#endif

// in case the values are not defined in config_buttons.h
// DO NOT alter the values here 
#ifndef CHOSEN_ADDITIONAL_BUTTON_0_FUNCTION
  #define CHOSEN_ADDITIONAL_BUTTON_0_FUNCTION FUNCTION_NULL
#endif
#ifndef CHOSEN_ADDITIONAL_BUTTON_1_FUNCTION
  #define CHOSEN_ADDITIONAL_BUTTON_1_FUNCTION FUNCTION_NULL
#endif
#ifndef CHOSEN_ADDITIONAL_BUTTON_2_FUNCTION
  #define CHOSEN_ADDITIONAL_BUTTON_2_FUNCTION FUNCTION_NULL
#endif
#ifndef CHOSEN_ADDITIONAL_BUTTON_3_FUNCTION
  #define CHOSEN_ADDITIONAL_BUTTON_3_FUNCTION FUNCTION_NULL
#endif
#ifndef CHOSEN_ADDITIONAL_BUTTON_4_FUNCTION
  #define CHOSEN_ADDITIONAL_BUTTON_4_FUNCTION FUNCTION_NULL
#endif
#ifndef CHOSEN_ADDITIONAL_BUTTON_5_FUNCTION
  #define CHOSEN_ADDITIONAL_BUTTON_5_FUNCTION FUNCTION_NULL
#endif
#ifndef CHOSEN_ADDITIONAL_BUTTON_6_FUNCTION
  #define CHOSEN_ADDITIONAL_BUTTON_6_FUNCTION FUNCTION_NULL
#endif

//optional additional buttons
int additionalButtonActions[MAX_ADDITIONAL_BUTTONS] = {
                          CHOSEN_ADDITIONAL_BUTTON_0_FUNCTION,
                          CHOSEN_ADDITIONAL_BUTTON_1_FUNCTION,
                          CHOSEN_ADDITIONAL_BUTTON_2_FUNCTION,
                          CHOSEN_ADDITIONAL_BUTTON_3_FUNCTION,
                          CHOSEN_ADDITIONAL_BUTTON_4_FUNCTION,
                          CHOSEN_ADDITIONAL_BUTTON_5_FUNCTION,
                          CHOSEN_ADDITIONAL_BUTTON_6_FUNCTION
};
unsigned long lastAdditionalButtonDebounceTime[MAX_ADDITIONAL_BUTTONS];  // the last time the output pin was toggled
unsigned long additionalButtonDebounceDelay = ADDITIONAL_BUTTON_DEBOUNCE_DELAY;    // the debounce time
bool additionalButtonRead[MAX_ADDITIONAL_BUTTONS];
bool additionalButtonLastRead[MAX_ADDITIONAL_BUTTONS];

char *customCommand1 = (char*) CUSTOM_COMMAND_1;
char *customCommand2 = (char*) CUSTOM_COMMAND_2;
char *customCommand3 = (char*) CUSTOM_COMMAND_3;
char *customCommand4 = (char*) CUSTOM_COMMAND_4;
char *customCommand5 = (char*) CUSTOM_COMMAND_5;
char *customCommand6 = (char*) CUSTOM_COMMAND_6;
char *customCommand7 = (char*) CUSTOM_COMMAND_7;


// *********************************************************************************

void displayUpdateFromWit(int multiThrottleIndex) {
  debug_print("displayUpdateFromWit(): keyapdeUseType "); debug_print(keypadUseType); 
  // debug_print(" menuIsShowing "); debug_print(menuIsShowing);
  // debug_print(" multiThrottleIndex "); debug_print(multiThrottleIndex);
  // debug_println("");
  if ( (keypadUseType==KEYPAD_USE_OPERATION) && (!menuIsShowing) 
  && (multiThrottleIndex==currentThrottleIndex) ) {
    writeOledSpeed();
  }
}

// dccexProtocol Delegate class
class MyDelegate : public DCCEXProtocolDelegate {
  
  public:
    void heartbeatConfig(int seconds) { 
      debug_print("Received heartbeat. From: "); debug_print(heartBeatPeriod); 
      debug_print(" To: "); debug_println(seconds); 
      heartBeatPeriod = seconds;
    }
    void receivedServerVersion(int major, int minor, int patch) {
      debug_print("\n\nReceived version: ");
      debug_print(major);
      debug_print(".");
      debug_print(minor);
      debug_print(".");
      debug_println(patch);
    }
    void receivedMessage(char* message) {
      debug_print("Broadcast Message: ");
      debug_println(message);
      broadcastMessageText = String(message);
      broadcastMessageTime = millis();
      refreshOled();
    }
    virtual void receivedLocoUpdate(Loco* loco) {  // roster locos only
      debugLocoSpeed("receivedLocoUpdate: ", loco); 
      _processLocoUpdate(loco);
    }
    void receivedLocoBroadcast(int address, int speed, Direction direction, int functionMap) { // non-roster locos only
      debugLocoSpeed("receivedLocoBroadcast: ", address, LocoSourceEntry, speed, direction); 
      _processLocoBroadcast(address, speed, direction, functionMap);
    }
    void receivedTrackPower(TrackPower state) { 
      debug_print("Received TrackPower: "); debug_println(state);
      if (trackPower != state) {
        trackPower = state;
        // displayUpdateFromWit(-1); // dummy multithrottlehumm
        refreshOled();
      }
    }
    // void receivedIndividualTrackPower(TrackPower state, int track) { 
    //   debug_print("Received Indivdual TrackPower: "); 
    //   debug_print(state);
    //   debug_print(" : ");
    //   debug_println(track);
    // }
    void receivedRosterList() {
      debug_println("Received Roster List");
      _loadRoster();
    }
    void receivedTurnoutList() {
      Serial.println("Received Turnouts/Points list");
      _loadTurnoutList();
    }    
    void receivedRouteList() {
      Serial.println("Received Routes List");
      _loadRouteList();
    }
};

int getMultiThrottleIndex(char multiThrottle) {
    int mThrottle = multiThrottle - '0';
    if ((mThrottle >= 0) && (mThrottle<=5)) {
        return mThrottle;
    } else {
        return 0;
    }
}

char getMultiThrottleChar(int multiThrottleIndex) {
  return '0' + multiThrottleIndex;
}

WiFiClient client;
DCCEXProtocol dccexProtocol(MAX_BUFFER_SIZE, MAX_COMMAND_PARAMS);
MyDelegate myDelegate;
int deviceId = random(1000,9999);
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
void loop() {
  
  if (ssidConnectionState != CONNECTION_STATE_CONNECTED) {
    // connectNetwork();
    ssidsLoop();
    checkForShutdownOnNoResponse();
  } else {  
    if (dccexConnectionState != CONNECTION_STATE_CONNECTED) {
      witServiceLoop();
    } else {
      dccexProtocol.check();    // parse incoming messages
      dccexProtocol.getLists(true, true, true, false);

      setLastServerResponseTime(false);

      if (heartbeatCheckEnabled) {
        if (lastServerResponseTime+(heartBeatPeriod*4) < millis()/1000) {
          debug_print("Disconnected - Last:");  debug_print(lastServerResponseTime); debug_print(" Current:");  debug_println(millis()/1000);
          reconnect();
        } else if (lastServerResponseTime+(heartBeatPeriod) < millis()/1000) {
          requestHeartbeat();
        }
      }
    }
  }
  // char key = keypad.getKey();
  keypad.getKey();
  rotary_loop();

  additionalButtonLoop(); 
  
  if (useBatteryTest) { batteryTest_loop(); }

	// debug_println("loop:" );
}

// *********************************************************************************
//  Key press and Menu
// *********************************************************************************

void doKeyPress(char key, bool pressed) {
  debug_println("doKeyPress(): Start: "); 

  if (pressed)  { //pressed
    switch (keypadUseType) {
      case KEYPAD_USE_OPERATION:
        debug_print("key operation... "); debug_println(key);
        switch (key) {
          case '*':  // menu command
            menuCommand = "";
            if (menuCommandStarted) { // then cancel the menu
              resetMenu();
              writeOledSpeed();
            } else {
              menuCommandStarted = true;
              debug_println("Command started");
              writeOledMenu("");
            }
            break;

          case '#': // end of command
            debug_print("end of command... "); debug_print(key); debug_print ("  :  "); debug_println(menuCommand);
            if ((menuCommandStarted) && (menuCommand.length()>=1)) {
              doMenu();
            } else {
              if (!hashShowsFunctionsInsteadOfKeyDefs) {
                if (!oledDirectCommandsAreBeingDisplayed) {
                  writeOledDirectCommands();
                } else {
                  oledDirectCommandsAreBeingDisplayed = false;
                  writeOledSpeed();
                }
              } else {
                writeOledFunctionList(""); 
              }
            }
            break;

          case '0': case '1': case '2': case '3': case '4': 
          case '5': case '6': case '7': case '8': case '9':
            debug_print("number... "); debug_print(key); debug_print ("  cmd: '"); debug_print(menuCommand); debug_println("'");

            if (menuCommandStarted) { // append to the string

              if ((menuCharsRequired[key-48] == 0) && (menuCommand.length() == 0)) { // menu type is effectively a direct commands from this point
                menuCommand += key;
                doMenu();
              } else {
                if ((menuCharsRequired[menuCommand.substring(0,1).toInt()] == 1) && (menuCommand.length() == 1)) {  // menu type needs only one char
                  menuCommand += key;
                  doMenu();

                } else {  //menu type allows/requires more than one char
                  menuCommand += key;
                  writeOledMenu(menuCommand);
                }
              }
            } else {
              doDirectCommand(key, true);
            }
            break;

          default:  //A, B, C, D
            doDirectCommand(key, true);
            break;
        }
        break;

      case KEYPAD_USE_ENTER_WITHROTTLE_SERVER:
        debug_print("key: Enter wit... "); debug_println(key);
        switch (key){
          case '0': case '1': case '2': case '3': case '4': 
          case '5': case '6': case '7': case '8': case '9':
            witEntryAddChar(key);
            break;
          case '*': // backspace
            witEntryDeleteChar(key);
            break;
          case '#': // end of command
            if (witServerIpAndPortEntered.length() == 17) {
              dccexConnectionState = CONNECTION_STATE_ENTERED;
            }
            break;
          default:  // do nothing 
            break;
        }

        break;

      case KEYPAD_USE_ENTER_SSID_PASSWORD:
        debug_print("key: Enter password... "); debug_println(key);
        switch (key){
          case '0': case '1': case '2': case '3': case '4': 
          case '5': case '6': case '7': case '8': case '9':
            ssidPasswordAddChar(key);
            break;
          case '*': // backspace
            ssidPasswordDeleteChar(key);
            break;
          case '#': // end of command
              selectedSsidPassword = ssidPasswordEntered;
              encoderUseType = ENCODER_USE_OPERATION;
              keypadUseType = KEYPAD_USE_OPERATION;
              ssidConnectionState = CONNECTION_STATE_SELECTED;
            break;
          default:  // do nothing 
            break;
        }

        break;

      case KEYPAD_USE_SELECT_WITHROTTLE_SERVER:
        debug_print("key: Select wit... "); debug_println(key);
        switch (key){
          case '0': case '1': case '2': case '3': case '4':
            selectWitServer(key - '0');
            break;
          case '#': // show ip address entry screen
            dccexConnectionState = CONNECTION_STATE_ENTRY_REQUIRED;
            buildWitEntry();
            enterWitServer();
            break;
          default:  // do nothing 
            break;
        }
        break;

      case KEYPAD_USE_SELECT_SSID:
        debug_print("key ssid... "); debug_println(key);
        switch (key){
          case '0': case '1': case '2': case '3': case '4': 
          case '5': case '6': case '7': case '8': case '9':
            selectSsid(key - '0');
            break;
          case '#': // show found SSIds
            ssidConnectionState = CONNECTION_STATE_DISCONNECTED;
            keypadUseType = KEYPAD_USE_SELECT_SSID_FROM_FOUND;
            ssidSelectionSource = SSID_CONNECTION_SOURCE_BROWSE;
            // browseSsids();
            break;
          default:  // do nothing 
            break;
        }
        break;

      case KEYPAD_USE_SELECT_SSID_FROM_FOUND:
        debug_print("key ssid from found... "); debug_println(key);
        switch (key){
          case '0': case '1': case '2': case '3': case '4': 
            selectSsidFromFound(key - '0'+(page*5));
            break;
          case '#': // next page
            if (foundSsidsCount>5) {
              if ( (page+1)*5 < foundSsidsCount ) {
                page++;
              } else {
                page = 0;
              }
              writeOledFoundSSids(""); 
            }
            break;
          case '9': // show in code list of SSIDs
            ssidConnectionState = CONNECTION_STATE_DISCONNECTED;
            keypadUseType = KEYPAD_USE_SELECT_SSID;
            ssidSelectionSource = SSID_CONNECTION_SOURCE_LIST;
            break;
          default:  // do nothing 
            break;
        }
        break;

      case KEYPAD_USE_SELECT_ROSTER:
        debug_print("key Roster... "); debug_println(key);
        switch (key){
          case '0': case '1': case '2': case '3': case '4': 
          case '5': case '6': case '7': case '8': case '9':
            selectRoster((key - '0')+(page*5));
            break;
          case '#':  // next page
            if ( rosterSize > 5 ) {
              if ( (page+1)*5 < rosterSize ) {
                page++;
              } else {
                page = 0;
              }
              writeOledRoster(""); 
            }
            break;
          case '*':  // cancel
            resetMenu();
            writeOledSpeed();
            break;
          default:  // do nothing 
            break;
        }
        break;
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

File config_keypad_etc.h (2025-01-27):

//
// DO NOT alter this file
// 
// If you need to alter one of the defines in here, do so in config_buttons.h  NOT HERE
//

// Keypad + encoder + oLed config

// *******************************************************************************************************************
// encoder

// default Small ESP32
#ifndef ROTARY_ENCODER_A_PIN
    #define ROTARY_ENCODER_A_PIN 12
#endif
#ifndef ROTARY_ENCODER_B_PIN
    #define ROTARY_ENCODER_B_PIN 14
#endif
#ifndef ROTARY_ENCODER_BUTTON_PIN
    #define ROTARY_ENCODER_BUTTON_PIN 13
#endif

#ifndef ROTARY_ENCODER_VCC_PIN
    #define ROTARY_ENCODER_VCC_PIN -1 /* 27 put -1 of Rotary encoder Vcc is connected directly to 3,3V; else you can use declared output pin for powering rotary encoder */
#endif
#ifndef ROTARY_ENCODER_STEPS
    #define ROTARY_ENCODER_STEPS 2 //depending on your encoder - try 1,2 or 4 to get expected behaviour
#endif

// *******************************************************************************************************************
// keypad

// 4x3 keypad
#ifndef ROW_NUM
    #define ROW_NUM     4
#endif
#ifndef COLUMN_NUM
    #define COLUMN_NUM  3
#endif
#ifndef KEYPAD_KEYS
    #define KEYPAD_KEYS  {'1', '2', '3'}, {'4', '5', '6'}, {'7', '8', '9'}, {'*', '0', '#'}
#endif
#ifndef KEYPAD_ROW_PINS
    #define KEYPAD_ROW_PINS    {19, 18, 17, 16}
#endif
#ifndef KEYPAD_COLUMN_PINS
    #define KEYPAD_COLUMN_PINS { 4, 0, 2}
#endif


char keys[ROW_NUM][COLUMN_NUM] = {KEYPAD_KEYS};
byte pin_rows[ROW_NUM]      = KEYPAD_ROW_PINS; // GIOP19, GIOP18, GIOP5, GIOP17 connect to the row pins
byte pin_column[COLUMN_NUM] = KEYPAD_COLUMN_PINS;   // GIOP16, GIOP4, GIOP0 connect to the column pins

Keypad keypad = Keypad( makeKeymap(keys), pin_rows, pin_column, ROW_NUM, COLUMN_NUM );

#ifndef KEYPAD_DEBOUNCE_TIME
    #define KEYPAD_DEBOUNCE_TIME 10
#endif
#ifndef KEYPAD_HOLD_TIME
    #define KEYPAD_HOLD_TIME 200
#endif

// *******************************************************************************************************************
// additional / optional buttons hardware

// To use the additional buttons, adjust the functions assigned to them in config_buttons.h
#ifndef MAX_ADDITIONAL_BUTTONS
    #define MAX_ADDITIONAL_BUTTONS 7  // If you alter this number, you must also alter the additionalButtonActions array in DccExController.ino
#endif
#ifndef ADDITIONAL_BUTTONS_PINS
    #define ADDITIONAL_BUTTONS_PINS      {5,15,25,26,27,32,33}
#endif
#ifndef ADDITIONAL_BUTTONS_TYPE
    #define ADDITIONAL_BUTTONS_TYPE      {INPUT_PULLUP,INPUT_PULLUP,INPUT_PULLUP,INPUT_PULLUP,INPUT_PULLUP,INPUT_PULLUP,INPUT_PULLUP}
   // 34,35,36,39 don't have an internal pullup
#endif

int additionalButtonPin[MAX_ADDITIONAL_BUTTONS] =          ADDITIONAL_BUTTONS_PINS;
int additionalButtonType[MAX_ADDITIONAL_BUTTONS] =         ADDITIONAL_BUTTONS_TYPE;


#ifndef ADDITIONAL_BUTTON_DEBOUNCE_DELAY
    #define ADDITIONAL_BUTTON_DEBOUNCE_DELAY 50   // default if not defined in config_buttons.h
#endif

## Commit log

2023-12-27 Fix loading of the function labels
    [DccExController.ino, static.h]
2024-02-17 temporary solution for latching buttons
    - temporary solution for latching buttons
    - F1 and F2 default to momentary - can be overridden (see config_buttons_example.h)
2024-03-09 imporve debounce on encoder button
2024-03-10 bug fix + additional logging
    [DccExController.ino, static.h]
2024-03-17 button and display PIN configurations moved to defines that can be overridden in personal config_buttons_etc.h files
2024-05-21 support for optionally using a voltage divider to show the battery charge level
2024-05-26 added auto deep sleep on low battery
2024-06-01 - minor format change
    [WiTcontroller - optional buttons v0.1.fzz]
2024-06-02 doco update only
    [WiTcontroller - 4x4 keypad, Optional buttons v0.1.fzz, WiTcontroller - Optional battery monitor.fzz, WiTcontroller - optional buttons v0.1.fzz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]
2024-06-16 custom commands + ESP32 Board Library problem
    - support for 4x4 keypad
    - support for custom commands
    - workaround for the latest versions of the ESP32 Board Library (3.0.0 and later) have renamed an attribute.
    [DccExController.ino, actions.h, config_buttons_example.h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]
2024-06-17 automated fix for the ESP32 Board Library problem
    [config_buttons_example.h, static.h]
2025-01-27 momentary functions fix
    make roster momentary functions obey momentary if selected from the menu
    [DccExController.ino, actions.h, static.h]
2025-01-27 moved the battery indicator to the top row
    added the ``BATTERY_CONVERSION_FACTOR`` define
2025-01-27 added support for ``BATTERY_CONVERSION_FACTOR`` define
2025-01-28 bug fix for when using the Arduino IDE
    [DccExController.ino, Throttle.cpp, static.h]
2025-01-29 fix bug introduced by changes in v1.0.1 of the libra
    fix bug introduced by changes in v1.0.1 of the Protocol library such that the direction of non-roster locos could not be changed.
    [DccExController.ino, static.h]
2025-02-04 bug fix. roster entries >60 would cause a crash
    [DccExController.ino, static.h]
